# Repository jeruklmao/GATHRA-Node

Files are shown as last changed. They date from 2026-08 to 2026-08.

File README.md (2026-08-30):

# GATHRA Node

GATHRA Node firmware **2.1.1** measures flood-water distance and sends telemetry
to one GATHRA Gateway over **LoRa Protocol 3**. It runs on an ESP32-C3 Super
Mini with an SX1278, HY-SRF05 ultrasonic sensor, DHT22, PCF8563 RTC, battery
monitor, and active-HIGH buzzer.

The PCF8563 and AO3401A control the production hard-power lifecycle. Normal
polling does not use ESP deep sleep: firmware verifies the next RTC wake,
clears the active RTC interrupt only during the final shutdown transaction,
and then external power is removed from the switched electronics.

## Hardware

`include/board_pins.hpp` is the wiring authority.

| GPIO | Function |
| ---: | --- |
| 0 | battery ADC |
| 1, 3 | SX1278 RST, DIO0 |
| 4, 5, 6, 7 | SX1278 SCK, MISO, MOSI, NSS |
| 8, 9 | PCF8563 SDA, SCL |
| 10 | DHT22 data |
| 20, 21 | HY-SRF05 trigger, echo |
| 2 | active-HIGH buzzer |

The physical maintenance button pulls the power-latch gate low; it is not an
ESP32 input. A manual power-up establishes and verifies an RTC timer latch,
then opens the node-local maintenance access point. See
[hardware](docs/hardware/README.md) and [power management](docs/power-management.md).

## Measurement and telemetry

A normal timer wake performs this bounded sequence:

```text
battery -> DHT/environment -> ultrasonic burst -> filter/verify
        -> persist sequence -> Protocol 3 telemetry/ACK
        -> persist history/state -> program next RTC wake -> power off
```

The default ultrasonic burst uses seven pings with at least five valid samples.
Firmware calculates median distance and MAD, applies temperature/humidity sound
speed compensation when available, then uses Hampel filtering, rise/fall
confirmation, and EMA smoothing. `rawDistanceMm` is the burst median;
`acceptedDistanceMm` is the stable filtered value used for water-height
derivation.

`referenceDistanceMm` is an operator-configured installation datum. A value of
zero means it is unset. When both reference and accepted distance are available:

```text
waterHeightMm = referenceDistanceMm - acceptedDistanceMm
```

Protocol 3 telemetry includes raw and accepted distance, environmental and
battery measurements, filter/quality/health diagnostics, RTC and schedule
state, command result state, poll interval, and the Node reference distance.
The exact wire layout is documented in [protocol.md](docs/protocol.md).

The default poll interval is **10 minutes** and the configured range is 1–255
minutes. A measurement that requires a quicker follow-up is scheduled at the
one-minute minimum supported by the RTC timer.

## Commands and persistence

The Gateway can include one command in a matching ACK:

- `ENTER_MAINTENANCE_NOW`
- `SCHEDULE_MAINTENANCE_AT`
- `SET_POLL_INTERVAL_MINUTES`

Command receipt and result are persisted before reporting success. Repeated
command IDs return the stored result without repeating the side effect.

The `nvs_v2` partition stores validated configuration, persistent session and
next sequence, filter state, 512 measurement-history records, maintenance and
RTC state, command state, OTA markers, and bounded power diagnostics. These
records survive complete external power removal.

## Maintenance dashboard

Maintenance mode provides a self-contained node-local dashboard for status,
measurement, calibration, configuration, LoRa diagnostics, bounded logs,
history, OTA, reboot, and controlled power-off. Its configured lifetime is
60–300 seconds and defaults to 300 seconds; passive polling does not extend it.

History is bounded at every interface:

- `GET /api/history?offset=0&limit=12` returns chronological pages; default and
  maximum page size are 12.
- `GET /api/history/chart?series=rawDistanceMm&maxPoints=100` returns at most
  100 uniformly sampled points while retaining the endpoints.
- the dashboard loads history on entry or explicit refresh and does not poll
  full records in the background.

See [dashboard.md](docs/dashboard.md) for the current endpoint contract.

## OTA

Browser OTA writes PlatformIO's
`.pio/build/esp32-c3-devkitm-1/firmware.bin` to the inactive application slot.
A pending image is marked valid only after configuration, NVS, partition,
RTC, history, sensor, and radio initialization checks pass. OTA and maintenance
reboots preserve the active RTC latch and remaining maintenance deadline. See
[ota.md](docs/ota.md).

## Build and test

```bash
pio test -e native
pio run -e esp32-c3-devkitm-1
pio run -e hil
```

The `hil` profile forces maintenance mode for hardware checks. Hardware flashing
and battery-rail validation require a positively identified board and are not
performed by the automated commands. See [testing.md](docs/testing.md).

## Safety and security

Protocol 3 uses radio CRC but does not provide encryption or Node
authentication. Pairing is an operational allow-list. The maintenance dashboard
has no application-level login and must remain limited to the node-local WPA2
network.

GATHRA measurements and derived flood levels are modeled observations, not a
public-safety guarantee. Missing, uncertain, or stale information must never be
treated as evidence that an area is safe.

---

Copyright © 2026 GATHRA Project. All rights reserved.

Source code and documentation in this repository are publicly viewable for inspection, academic review, and evaluation. No permission is granted to reproduce, redistribute, modify, commercialize, or create derivative works except where explicitly permitted by the repository's license or by written permission from the copyright holder.

If you use GATHRA in academic or research work, please provide appropriate attribution to the GATHRA Project and its associated publications.

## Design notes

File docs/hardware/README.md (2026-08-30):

# Node hardware

`include/board_pins.hpp` is the current wiring authority. Runtime configuration
cannot override these pins.

## ESP32-C3 GPIO map

| GPIO | Net |
| ---: | --- |
| 0 | battery ADC |
| 1 | SX1278 RST |
| 3 | SX1278 DIO0 |
| 4 | SX1278 SCK |
| 5 | SX1278 MISO |
| 6 | SX1278 MOSI |
| 7 | SX1278 NSS/CS |
| 8 | PCF8563 SDA |
| 9 | PCF8563 SCL |
| 10 | DHT22 data |
| 20 | HY-SRF05 trigger |
| 21 | HY-SRF05 echo |
| 2 | active-HIGH buzzer |

There is no ESP push-button GPIO.

## Power topology

The battery powers the PCF8563 continuously. An AO3401A switches the ESP32-C3,
radio, sensors, and boost circuitry. The push button and PCF8563 open-drain INT
can pull the MOSFET gate low to power the switched rail. Firmware controls
shutdown by configuring and clearing RTC timer/alarm interrupt state.

PCF8563 I2C uses the ESP32 internal pull-ups while the switched electronics are
powered. USB powers the ESP32-C3 and therefore cannot validate removal of the
battery-switched rail.

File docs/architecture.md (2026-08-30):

# Node architecture

## State flow

```text
BOOT
  classify reboot marker, RTC alarm flag, then RTC timer flag
  -> POLL or MAINTENANCE

POLL
  acquire -> filter/verify -> persist sequence -> TELEMETRY
  -> matching ACK_COMMAND -> UTC/command -> COMMAND_RESULT
  -> persist history/state -> program and verify next wake
  -> release RTC flag -> external power removal

MAINTENANCE
  bounded dashboard/config/history/OTA
  -> fixed configured deadline, maximum 300 seconds
  -> persist -> program and verify next wake -> release RTC flag
```

`NodeApp` orchestrates isolated sensor, filter, protocol, command, RTC, storage,
buzzer, OTA, web, radio, and power modules.

## Boot and power

PCF8563 status is read before flag modification. Classification precedence is:

1. a valid persisted OTA or maintenance-reboot marker;
2. an alarm flag matching the pending UTC maintenance target;
3. the timer flag;
4. successful RTC communication with neither flag, indicating manual power-up;
5. unknown.

The active RTC flag remains asserted while firmware works. The final power-off
transaction persists state, programs and verifies the next timer and any
pending alarm, stops network/radio activity, completes buzzer output, and then
performs the only flag-release write. A verification failure retains the latch
and enters bounded recovery.

## Persistence

The `nvs_v2` partition contains validated configuration, persistent protocol
identity, filter memory, schedule and command state, reboot/deadline state,
power diagnostics, and measurement history. Sequence allocation commits the
next value before radio transmission.

History is a 512-slot circular store with 38-byte checked records and
alternating metadata generations. Corrupt records are skipped. Dashboard reads
use 12-entry pages or at most 100 sampled chart points.

## Sensors and filtering

The measurement path performs bounded echo checks, a configurable sonar burst,
median and MAD calculation, environment-compensated sound speed, Hampel-style
temporal filtering, rise/fall verification, and EMA. Filter memory survives
hard-power cycles. A suspicious raw change cannot replace the accepted distance
until confirmation policy permits it.

## Watchdog and OTA

The loop-task watchdog remains active. Sensor, I2C, radio, HTTP, and OTA work
has bounded waits and yields during long operations. Dashboard responses use
bounded data sets and a fixed socket deadline. OTA validates a pending image
only after required local configuration, storage, RTC, sensor, radio, history,
and partition checks succeed.

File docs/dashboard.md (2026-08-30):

# Node maintenance dashboard

Maintenance mode opens a node-local WPA2 access point and serves its dashboard
at `http://192.168.4.1/`. The dashboard has no additional login, must not be
bridged to an untrusted network, and never sends credentials in status JSON.

The configured maintenance lifetime is 60–300 seconds and defaults to 300
seconds. Passive status, history, and log reads do not extend the deadline.

## Current functions

The dashboard shows firmware **2.1.1**, Protocol **3**, Node and boot identity,
maintenance deadline, PCF8563/RTC state, next poll and maintenance schedule,
persistent sequence and command state, sensor/calibration values, LoRa result,
history utilization, OTA state, and power diagnostics.

Operator actions include:

- run the production measurement and filtering path;
- capture, set, or clear the reference distance;
- validate and save sensor, filtering, battery, radio, ACK, poll, and
  maintenance configuration;
- send a real Protocol 3 test packet;
- install OTA firmware, reboot while preserving maintenance, or finish
  maintenance through the verified power-off transaction.

Configuration changes are validated before persistence. Radio settings are
tested before they replace the active settings.

## Bounded history API

`GET /api/history?offset=0&limit=12` returns chronological full records. The
default and maximum page size are both 12; larger limits are clamped. The
response contains `count`, `capacity`, `offset`, `limit`, `returned`,
`hasPrevious`, `hasNext`, nullable `nextOffset`, and `entries`. Previous and
Next controls request only the selected page.

`GET /api/history/chart?series=rawDistanceMm&maxPoints=100` returns compact
chronological chart entries. The default and maximum are 100 points. When the
ring is larger, points are distributed uniformly and retain the earliest and
latest endpoints. Supported series are:

- `rawDistanceMm`
- `acceptedDistanceMm`
- `waterHeightMm`
- `temperatureC`
- `humidityPercent`
- `batteryMv`

Chart entries use `s` for sequence, nullable `v` for value, and numeric `f` for
filter state. Both history endpoints have bounded NVS work and JSON size.
Responses are written in 512-byte chunks with a 2.5-second request deadline.
The dashboard loads history on entry or explicit refresh; status polling never
scans the history ring.

## Buzzer

GPIO2 is active HIGH. Current patterns are one short poll-start beep, two short
manual-latch beeps, a short maintenance indicator every three seconds, two
short success beeps, three short error/no-ACK beeps, and one longer maintenance
shutdown beep. Firmware drives the pin LOW before releasing external power.

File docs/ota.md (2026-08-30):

# Node OTA and rollback

Browser OTA is available only in maintenance mode and writes the inactive partition. The 4 MiB layout contains ota_0 and ota_1 at 0x10000 and 0x190000, each 0x180000 bytes, with otadata at 0xE000.

Before accepting a reboot, firmware verifies that a PCF level latch is active, persists expectedReboot=OTA_REBOOT, retains the maintenance active/deadline state, and leaves TF/AF untouched. Upload chunks service the enabled loop watchdog without disabling protection.

On reboot, the marker takes precedence over AF/TF and selects OTA_REBOOT maintenance. A PENDING_VERIFY image is marked valid only after configuration, v2 NVS, PCF communication, history, sensors and SX1278 initialization pass. ESP-IDF rollback remains enabled; the rollback-test build deliberately fails validation and must roll back to the other valid slot.

If OTA occurs during an AF-held scheduled-maintenance window, the visible boot
reason remains `OTA_REBOOT` as required by precedence. At shutdown the firmware
re-evaluates the retained AF and authoritative UTC target without the reboot
override, completes the one-shot schedule, and only then clears AF.

A maintenance dashboard reboot uses the same flow with MAINTENANCE_REBOOT. The marker is consumed after classification; the persisted UTC deadline prevents either reboot from restarting an unlimited maintenance period.

USB OTA validates register/state/reboot logic only. A battery-only test is needed to prove that the MOSFET latch remains asserted across reset and can still be released afterward.

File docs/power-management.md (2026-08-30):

# Hard-power management

The PCF8563 is battery-powered continuously. ESP32-C3, SX1278, sensors, and boost circuitry are behind an AO3401A P-channel MOSFET. A 100 kΩ resistor pulls its gate high (off); the manual button or PCF8563 open-drain INT pulls it low (on). The ESP has no gate or button GPIO.

INT uses level mode (TI_TP=0). TIE+TF holds a timer boot; AIE+AF holds a scheduled-alarm boot. Flags are deliberately left set during work.

## Manual latch

A manual cold-power boot has neither AF nor TF. Firmware configures the timer at 64 Hz with value 8 (about 125 ms), TIE enabled, and level mode. It polls until TF and the control bits read back, with a one-second bound. Only then it emits two 100 ms beeps and declares that the operator can release the button.

## Normal timer

Poll interval is stored as 1–255 minutes, default 10. Normal wakes use source 1/60 Hz and the configured count. A pending maintenance alarm remains armed simultaneously.

## Final transaction

1. stop accepting maintenance operations;
2. persist state, filter, history, command, and diagnostics;
3. program the normal timer while preserving TF/AF;
4. preserve and verify a pending alarm, or defer completed active-alarm disable;
5. validate timer/alarm readback;
6. sleep radio and stop Wi-Fi;
7. flush logs and emit one 300 ms maintenance shutdown beep when applicable;
8. drive buzzer LOW;
9. atomically clear only active release flags and disable AIE for a completed alarm;
10. expect external power loss.

Step 9 is the point of no return. Failure before it retains the current latch and enters recovery. USB may keep the ESP running after step 9 and is not evidence of hard power-off.

On battery power, a successful step 9 normally removes the rail before a final
NVS confirmation write can complete. The event is stored first with
`flagClearAttempted=true`; the next genuine ESP `POWER_ON` boot reconciles the
prior record to `flagClearSucceeded=true`. Software, watchdog, and OTA resets do
not count as that independent evidence.

If AF becomes due during a TF-held operation, AF is preserved and a scheduled maintenance lifetime begins; it is not discarded during normal timer rearming.

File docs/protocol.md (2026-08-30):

# GATHRA LoRa Protocol 3

Firmware 2.1.1 uses Protocol 3 exclusively. All multi-byte integers are unsigned
big-endian unless marked signed; firmware encodes fields individually and never
transmits a C++ struct. SX1278 CRC is enabled, but Protocol 3 does not provide
HMAC, encryption, or node authentication.

## Common header

Let N be nodeIdLength and P = 5 + N.

| Offset | Size | Field | Value |
| ---: | ---: | --- | --- |
| 0 | 2 | magic | ASCII GT (47 54) |
| 2 | 1 | protocolVersion | 03 |
| 3 | 1 | messageType | 01 telemetry, 02 ACK_COMMAND, 03 COMMAND_RESULT |
| 4 | 1 | nodeIdLength | 1–24 |
| 5 | N | nodeId | ASCII A–Z, a–z, 0–9, hyphen, underscore |

Packets with a wrong version, malformed ID, unexpected length, invalid enum, reserved flag bit, or trailing byte are rejected.

## TELEMETRY (01)

The payload is 57 bytes, so total length is 62 + N. The maximum packet is 86 bytes for a 24-byte Node ID and fits the 96-byte radio buffer.

| Relative to P | Size | Field | Encoding |
| ---: | ---: | --- | --- |
| 0 | 4 | persistentSessionId | uint32 |
| 4 | 4 | sequence | uint32 |
| 8 | 4 | medianEchoUs | uint32 |
| 12 | 4 | rawDistanceMm | uint32 |
| 16 | 4 | acceptedDistanceMm | uint32 |
| 20 | 2 | madMm | uint16 |
| 22 | 2 | temperatureCentiC | int16 two's complement |
| 24 | 2 | humidityCentiPercent | uint16 |
| 26 | 2 | batteryMv | uint16 |
| 28 | 1 | validSamples | uint8 |
| 29 | 1 | totalSamples | uint8 |
| 30 | 1 | filterState | enum below |
| 31 | 2 | qualityFlags | bit mask |
| 33 | 2 | healthFlags | bit mask |
| 35 | 1 | bootReason | enum below |
| 36 | 1 | rtcState | enum below |
| 37 | 4 | rtcUnixTime | UTC seconds, or 0 when untrusted |
| 41 | 1 | pollIntervalMinutes | 1–255 |
| 42 | 1 | scheduleState | enum below |
| 43 | 4 | scheduledMaintenanceUnix | UTC seconds, or 0 for NONE |
| 47 | 4 | lastCommandId | 0 when command type is NONE |
| 51 | 1 | lastCommandType | command enum |
| 52 | 1 | lastCommandResult | result enum, FF for NONE |
| 53 | 4 | referenceDistanceMm | uint32 calibration reference; absolute offset 58 + N |

Sentinels: distance = FFFFFFFF, temperature = 8000, humidity = FFFF. `referenceDistanceMm=0` means calibration is not configured; every non-zero uint32 value is preserved exactly. Invalid RTC states require rtcUnixTime=0. Schedule state NONE requires scheduledMaintenanceUnix=0.

Filter states: 0 STABLE, 1 ACCEPTED, 2 VERIFY_RISE, 3 VERIFY_FALL, 4 TRANSIENT_REJECTED, 5 CHANGE_CONFIRMED, 6 UNCERTAIN, 7 INVALID.

Boot reasons: 0 RTC_TIMER, 1 RTC_SCHEDULED_MAINTENANCE, 2 MANUAL_BUTTON, 3 MAINTENANCE_REBOOT, 4 OTA_REBOOT, 5 UNKNOWN.

RTC states: 0 VALID, 1 INVALID_VL, 2 UNINITIALIZED, 3 I2C_ERROR. Schedule states: 0 NONE, 1 PENDING, 2 COMPLETED, 3 FAILED.

Quality bits: bit0 environment compensation, bit1 raw distance valid, bit2 accepted distance valid, bit3 installation limits applied, bit4 verification performed.

Health bits: bit0 sonar invalid, bit1 DHT invalid, bit2 environment stale, bit3 battery low, bit4 battery critical, bit5 radio error, bit6 unacknowledged, bit7 transient, bit8 uncertain, bit9 calibration missing, bit10 sensor degraded, bit11 battery ADC invalid.

## ACK_COMMAND (02)

The fixed ACK payload is 19 bytes followed by L command bytes; total length is 24 + N + L.

| Relative to P | Size | Field |
| ---: | ---: | --- |
| 0 | 4 | persistentSessionId |
| 4 | 4 | telemetry sequence |
| 8 | 4 | gatewayUnixTime |
| 12 | 1 | flags; bit0=timeValid, all others zero |
| 13 | 4 | commandId |
| 17 | 1 | commandType |
| 18 | 1 | commandPayloadLength |
| 19 | L | command payload |

When timeValid is zero, gatewayUnixTime must be zero. Identity must match nodeId, persistentSessionId, and sequence exactly.

| Command | Code | L | Payload |
| --- | ---: | ---: | --- |
| NONE | 0 | 0 | commandId must be 0 |
| ENTER_MAINTENANCE_NOW | 1 | 0 | none |
| SCHEDULE_MAINTENANCE_AT | 2 | 4 | UTC Unix seconds |
| SET_POLL_INTERVAL_MINUTES | 3 | 1 | 1–255 |

Gateway UTC is generated immediately before ACK construction. A command stays pending until a matching COMMAND_RESULT arrives.

## COMMAND_RESULT (03)

The payload is 15 bytes; total length is 20 + N.

| Relative to P | Size | Field |
| ---: | ---: | --- |
| 0 | 4 | persistentSessionId |
| 4 | 4 | commandId |
| 8 | 1 | commandType |
| 9 | 1 | resultCode |
| 10 | 1 | effectivePollIntervalMinutes |
| 11 | 4 | effective scheduled-maintenance UTC |

Result codes: 0 APPLIED, 1 ALREADY_APPLIED, 2 INVALID_ARGUMENT, 3 RTC_UNAVAILABLE, 4 RTC_TIME_UNTRUSTED, 5 SCHEDULE_UNREPRESENTABLE, 6 STORAGE_ERROR, 7 INTERNAL_ERROR.

The Gateway sends no ACK for this packet. It repeats an unconfirmed command in later telemetry ACKs. The Node persists receipt before applying, persists the result before reporting it, and re-sends the stored result for a duplicate command ID without repeating the side effect.

## Session and sequence safety

persistentSessionId is generated once and survives timer power cycles, manual cycles, resets, and OTA. Only an explicit identity/protocol-state reset may replace it. The Node reads nextSequence, increments and persists it before transmission. Power loss can create a gap but cannot reuse an allocated sequence. Gateway deduplication key is nodeId + persistentSessionId + sequence.

## Scheduled alarm constraints

The PCF8563 alarm has minute, hour, day-of-month, and weekday comparators—no month or year. GATHRA enables minute/hour/day and disables weekday. The NVS UTC target remains authoritative. Targets must be minute-aligned, at least 60 seconds ahead, and no more than 27 days ahead; otherwise the command returns SCHEDULE_UNREPRESENTABLE. On AF wake the Node also requires valid RTC UTC and a target match within the bounded five-minute window.

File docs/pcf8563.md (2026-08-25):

# PCF8563 integration

The production driver is lib/rtc/pcf8563.hpp/.cpp and uses the NXP PCF8563 data sheet as register authority.

## Electrical setup

Address is 0x51. SDA=GPIO8 and SCL=GPIO9. There are intentionally no always-powered external I2C pull-ups; firmware selects INPUT_PULLUP before starting Wire at 100 kHz and uses a 50 ms bus timeout.

## Registers and semantics

Control_status_1 is 00h. Control_status_2 is 01h: bit4 TI_TP, bit3 AF, bit2 TF, bit1 AIE, bit0 TIE. TI_TP=0 selects level behavior. AF/TF writes are logical-AND: writing zero clears that flag and writing one preserves it. Read-modify-write helpers explicitly preserve the other flag.

Time registers 02h–08h are BCD. Seconds bit7 is VL and makes time untrusted. The driver reports VALID, INVALID_VL, UNINITIALIZED, or I2C_ERROR and never exports invalid calendar bytes as UTC.

Alarm registers 09h–0Ch provide minute, hour, day, and weekday only. Timer control 0Eh selects 4096 Hz, 64 Hz, 1 Hz, or 1/60 Hz; timer value is 0Fh.

Every critical timer/alarm/time write has readback validation. The final release helper can atomically clear selected flags and disable AIE for a completed one-shot alarm.

## Scheduling policy

UTC is stored in the RTC. A trusted Gateway ACK sets the clock when invalid or when absolute drift exceeds five seconds. The last successful sync is persisted.

A one-shot maintenance target is accepted only if minute-aligned, 60 seconds to 27 days in the future, and representable in years 2000–2099. Minute/hour/day are programmed, weekday is disabled, and the full UTC target stays in NVS. AF wake is accepted only when valid RTC time matches that target within five minutes; this prevents recurring month/year ambiguity from silently becoming maintenance.

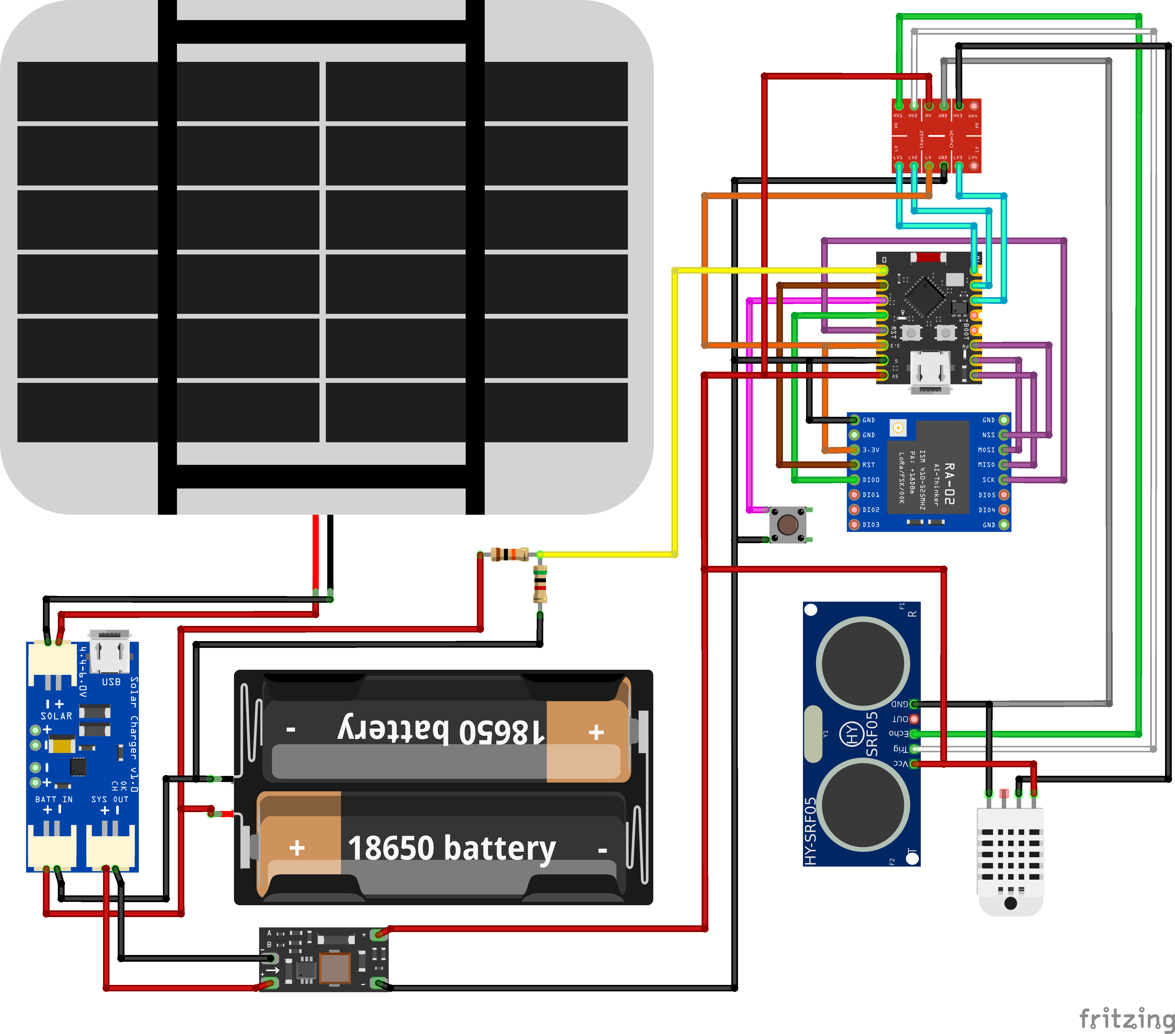
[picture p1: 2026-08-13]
docs/hardware/GATHRA_bb.png

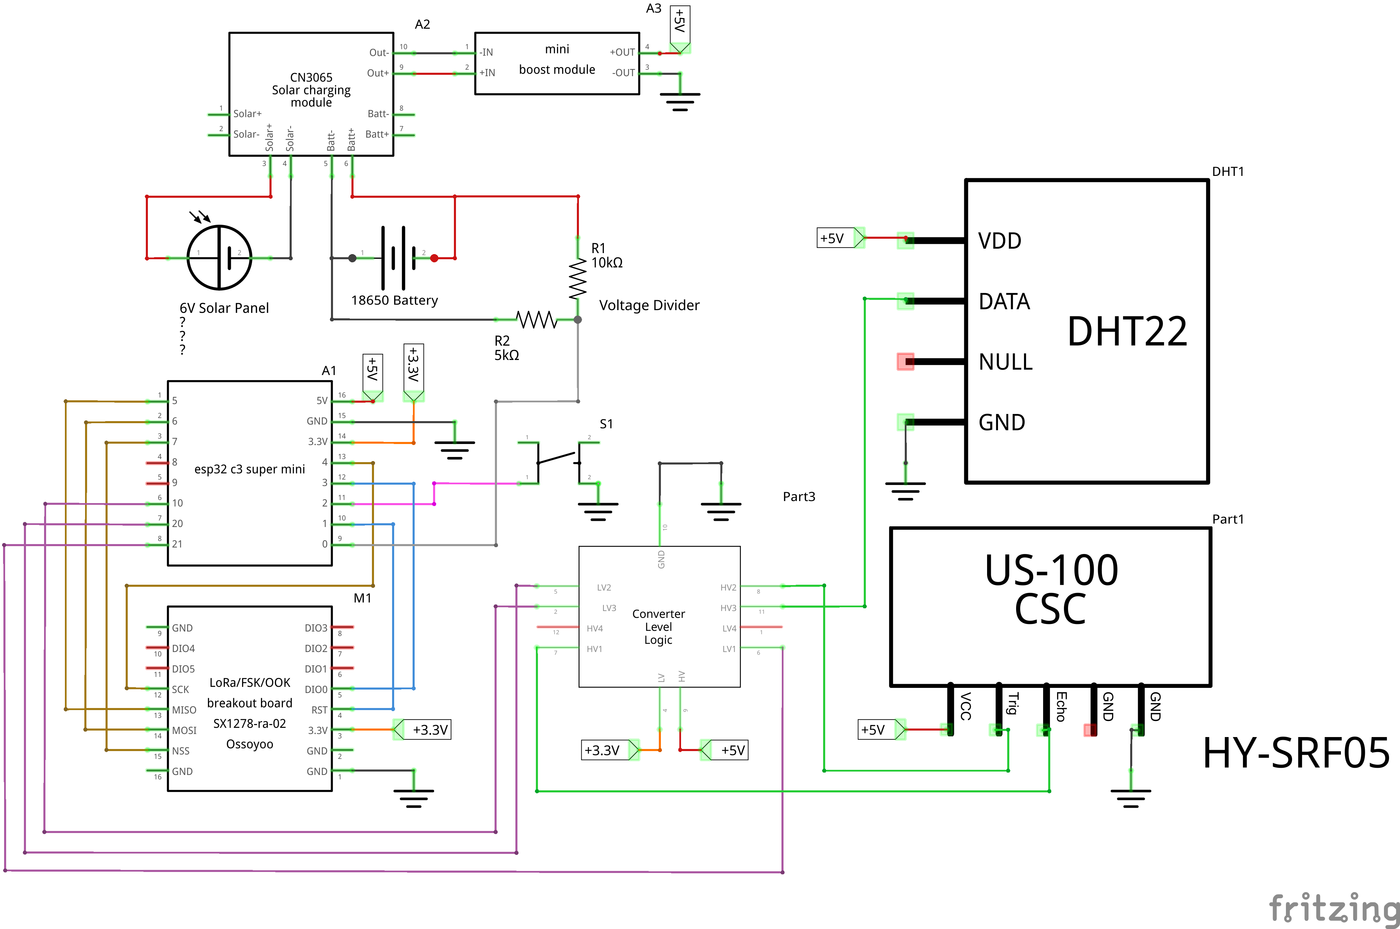
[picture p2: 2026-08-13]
docs/hardware/GATHRA_schem.png

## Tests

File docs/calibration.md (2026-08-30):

# Calibration

Calibration is an operator action in the maintenance dashboard. Place the
monitored surface at the installation datum, run **Measure Now** until the
accepted distance is stable, then capture that value or enter
`referenceDistanceMm` explicitly.

The Node derives:

```text
waterHeightMm = referenceDistanceMm - acceptedDistanceMm
```

A zero reference means calibration is unset. Water height is then unavailable
and the calibration health flag is set; firmware does not invent a zero height.

The production measurement path uses physical echo validation, a seven-ping
median/MAD burst, DHT-based sound-speed compensation, Hampel filtering,
rise/fall confirmation, and EMA. The accepted distance and filter baseline are
persisted in NVS across RTC-controlled hard-power cycles.

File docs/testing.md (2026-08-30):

# Node testing

## Automated checks

```bash
pio test -e native
pio run -e esp32-c3-devkitm-1
pio run -e hil
```

Native tests cover Protocol 3 golden bytes and rejection cases, commands and
idempotency, RTC calendar/timer/alarm logic, boot precedence, configuration,
persistent session/sequence safety, filtering, NVS history recovery, and the
bounded history pagination/chart algorithms.

The production build compiles the ESP32-C3 firmware. The `hil` build forces
maintenance mode while retaining real boot classification and peripherals.
Neither command flashes hardware.

## Dashboard bounded-response validation

With a full 512-record ring:

1. request status, configuration, and logs independently;
2. load the dashboard, a 100-point chart, and a 12-entry history page;
3. navigate all pages and verify chronological order;
4. keep the browser open for the complete maintenance lifetime;
5. connect a client that does not read a history response and verify the
   request closes within 2.5 seconds;
6. disconnect during a chart response, reconnect, and verify status remains
   responsive;
7. verify maintenance ends at its original deadline and no watchdog reset
   occurs.

## Hardware validation

Use the exact USB serial by-id path after mapping the board. USB can validate
register, state, radio, sensor, dashboard, and OTA logic, but it cannot prove
external power removal because USB powers the ESP32-C3.

Battery-only validation must confirm:

- the manual button establishes a verified RTC latch before it is released;
- maintenance remains available for the configured fixed lifetime;
- normal timer wakes transmit and then remove the switched rail;
- command and scheduled-alarm maintenance paths retain and release the correct
  RTC flags;
- OTA returns to maintenance, validates the selected slot, and preserves the
  remaining deadline;
- the configured poll interval is restored to the intended operational value.

Do not flash hardware, alter radio defaults, or change field configuration
without explicit operator authorization.

## Invariants

- Program and verify the next wake before clearing the power-holding flag.
- Persist `nextSequence` before transmission; gaps are allowed, reuse is not.
- Persist command receipt before applying it and persist the result before
  reporting `APPLIED`.
- Sensor, radio, or ACK failure must still lead to a bounded next-wake attempt.
- If next-wake verification fails, retain the latch and enter bounded recovery.

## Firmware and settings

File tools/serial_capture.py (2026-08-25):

#!/usr/bin/env python3
"""Bounded reconnecting serial capture for reset and power-cycle HIL runs."""

import argparse
import os
import sys
import time

import serial


def main() -> int:
    parser = argparse.ArgumentParser()
    parser.add_argument("--port", required=True)
    parser.add_argument("--baud", type=int, default=115200)
    parser.add_argument("--duration", type=float, default=30.0)
    parser.add_argument("--reset", action="store_true")
    args = parser.parse_args()
    deadline = time.monotonic() + args.duration
    connection = None
    while time.monotonic() < deadline:
        if connection is None:
            if not os.path.exists(args.port):
                time.sleep(0.05)
                continue
            try:
                connection = serial.Serial(args.port, args.baud, timeout=0.1)
                print(f"[capture] opened {args.port}", flush=True)
                if args.reset:
                    connection.rts = True
                    time.sleep(0.2)
                    connection.rts = False
                    time.sleep(0.3)
                    args.reset = False
            except (OSError, serial.SerialException):
                connection = None
                time.sleep(0.05)
                continue
        try:
            data = connection.read(4096)
            if data:
                sys.stdout.write(data.decode("utf-8", errors="replace"))
                sys.stdout.flush()
        except (OSError, serial.SerialException) as error:
            print(f"\n[capture] disconnected: {error}", flush=True)
            try:
                connection.close()
            except (OSError, serial.SerialException):
                pass
            connection = None
    if connection is not None:
        connection.close()
    return 0


if __name__ == "__main__":
    raise SystemExit(main())

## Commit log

2026-08-13 feat: implement GATHRA Node firmware v1.0.0
    [partitions.csv]
2026-08-13 docs: add production hardware and validation records
    [GATHRA.fzz]
2026-08-13 docs: correct battery ADC HIL result
2026-08-25 feat: migrate node to protocol v2 hard power control
    [partitions.csv]
2026-08-26 feat: transmit calibration reference in protocol v3
2026-08-28 Fix Node dashboard watchdog with bounded history responses
    Firmware 2.1.0 materialized all 512 NVS history entries into one
    ArduinoJson document and sent the 10,106 byte body synchronously via
    WiFiClient, blocking loopTask under socket backpressure/EAGAIN until
    TASK_WDT. 2.1.1 bounds history work and socket I/O:
    - Paginate /api/history to 12 entries max with offset/limit/hasNext
    metadata and clamped limit handling.
    - Add /api/history/chart with max 100 downsampled points retaining
    endpoints for six series and compact s/v/f keys.
    - Restrict history loads to explicit dashboard actions; status polling
    never scans history.
    - Send dashboard HTML and JSON in 512-byte nonblocking chunks with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
2026-08-30 Update documentation for current GATHRA implementation
